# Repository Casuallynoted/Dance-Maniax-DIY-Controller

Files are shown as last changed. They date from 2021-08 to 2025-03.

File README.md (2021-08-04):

# Dance-Maniax-DIY-Controller
A DIY solution for creating a Dance Maniax controller, I wound up spending less than $40-50 on the whole thing.

# Requirements:

-Teensy 2.0 (This is what I used, but any microcontroller/arduino could theoretically be used for this)

-Four Sharp GP2Y0A21YK0F sensors (can also be used with other IR sensors from Sharp but this one has the farthest range)

-Soldering iron and solder

-A computer to program the microcontroller, but if you're using Stepmania you probably already have this!

# Optional, but always great to have:

-The Teensy 2.0 board uses a mini usb cable to connect to a computer but doesn't include one in the box. Other controllers may require different cable types so do your research!

-I wound up deciding to get Male to Female jumper cables to extend the sensors further out than the provided cables do. I used the ones here: https://www.amazon.com/gp/product/B06XRV92ZB/ref=ppx_yo_dt_b_asin_title_o00_s00?ie=UTF8&psc=1

-Respirator, no solder fumes for me!

-Helping Hands to hold the board while soldering (and while it was still in the DIY phase this doubled as my controller stand for a while)

-I'm working on a 3D-printable enclosure to make everything look nice and neat. No more wires! Will update with the model and printing instructions as soon as it's available.

# Hardware Setup

1. Once you've got all your materials, you'll want to begin by taking a look at the board you're using and the wiring diagram for the sensor. In this case if you're using a Teensy 2.0 and Sharp GP2Y0A21YK0F, you'll want to view these documents:

https://www.pololu.com/file/0J85/gp2y0a21yk0f.pdf
https://www.pjrc.com/teensy/card2b_rev5_web.pdf

Notice how the motion sensors have three wires- one for ground, one for power (vcc), and one for the actual data connection. Note which ones they are on the sensors as we don't want to solder the wrong wires into the wrong place. On our Teensy board, these will be going into the Ground, VCC, and A1-4 holes. Our sensors will all be sharing a single Ground and VCC hole, but we'll be soldering them one by one to the data holes.

2. We'll begin by heating up the soldering iron and readying the solder. Begin by getting all four ground cables into the Ground hole and creating a solder joint going out the bottom. I won't go too into detail about the soldering process but definitely view some soldering tutorials on YouTube if you have not soldered before. These should be pretty easy joints to do, so no stress!

Of course, once you're all done you'll want to do the same for the VCC/Power cables, all in one hole and soldered in nice and easy. We'll want to finish by soldering in A1, followed by A2-4. Make sure you don't combine two wires into the A holes. Just one hole per wire for this one. Once you're done, you should have six joints in total.

3. Once you're all done soldering, you're going to want to pick two sensors that will make up the left part of your controller, and two sensors that will make up the right part. They'll be back-to-back on top of each other with one sensor facing up toward the ceiling and the other facing down toward the floor. For now, I secured mine with just a bit of tape, and then used my helping hands to hold the combined sensors upright for play. However, I'm working on a 3D printable model that can be used to screw the sensors into a secure arcade-inspired enclosure that can be attached to a tripod mount. I figure it should make everything a lot easier going forward. For now, do what works best for you and find a good way to keep those sensors together and in a place where you can use them.

# Software Setup

Woot! You made it to the software side of things! This is where things get even easier! 

1. Once you've got your soldering out of the way, plug your usb connector into the microcontroller and your computer. We'll want to download the Arduino software (or if using a Teensy, Teensyduino). You can find the software here: https://www.pjrc.com/teensy/td_download.html. Users on Windows and Linux will have to download the official Arduno software and install Teensyduino on top of it, while Mac users will be able to just install Teensyduino.

2. Since the code is already premade, download the zip file for this repository. You can go ahead and open the Sharp_IR_DMX.ino file in the Arduino software. 
 
3. Select your board type in the Tools menu under Tools -> USB Type. If using a Teensy 2.0, we'll use Teensyduino -> Teensy 2.0. Set the USB type to "Keyboard + Mouse + Joystick", and make sure your Teensy is selected under the section called "Port".

4. We'll want to install the SharpIR library, because it tells our Teensy how to communicate back and forth with the motion sensors. To do this, we can go to Tools -> Manage Libraries, and make sure SharpIR is installed. If not, search for and install it.

5. Once that's all installed, we can go ahead and click verify on our code. It shouldn't produce any errors here, but if it does definitely post an issue on the github and I'll see what I can do to help! If all passes, go ahead and click the upload button. You may be asked to click the button once on the teensy to put it into programming mode. 

Note: The values used in this file are based on my play, but may not be accurate to your situation. If you notice that the sensors are too sensitive or not sensitive enough during play, adjust the lines that say "if average(number of sensor) > 100" and change that number to something higher or lower to adjust the sensitivity. Lower than 100 will typically trigger game button presses more often in response to motion, while higher will typically trigger game button presses less.

6. Once it has programmed and restarted, your controller is now off to the races! You can test it using build in utilities like Windows joystick testing settings, or you can go right into stepmania's input test and see what it turns up. From here, you can map the controller as you usually would. Congrats, you're up and running with a Dance Maniax controller!

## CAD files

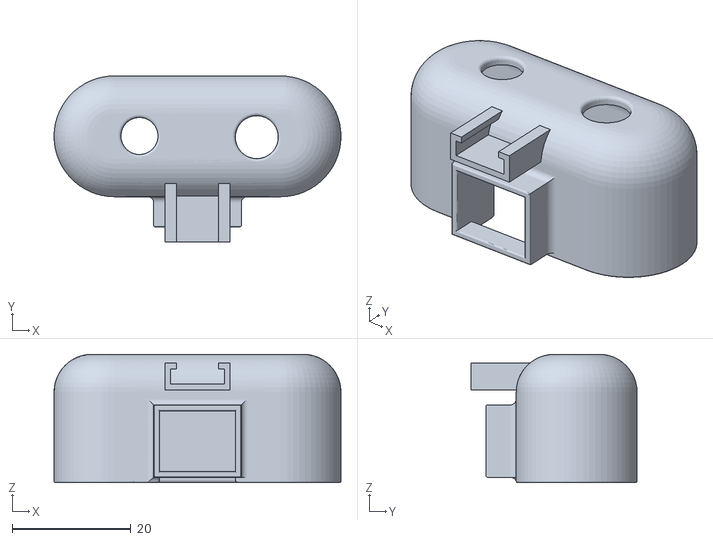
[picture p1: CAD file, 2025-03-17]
3D Printable STLs/sensor case.STL
48.3 x 27.9 x 21.6

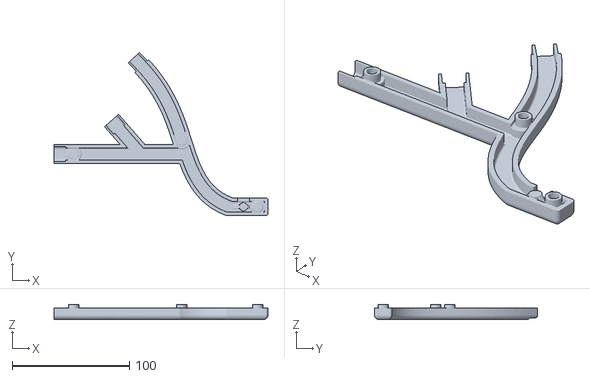
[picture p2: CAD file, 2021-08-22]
3D Printable STLs/Upper Left Arm.STL
182.7 x 139.3 x 13.0

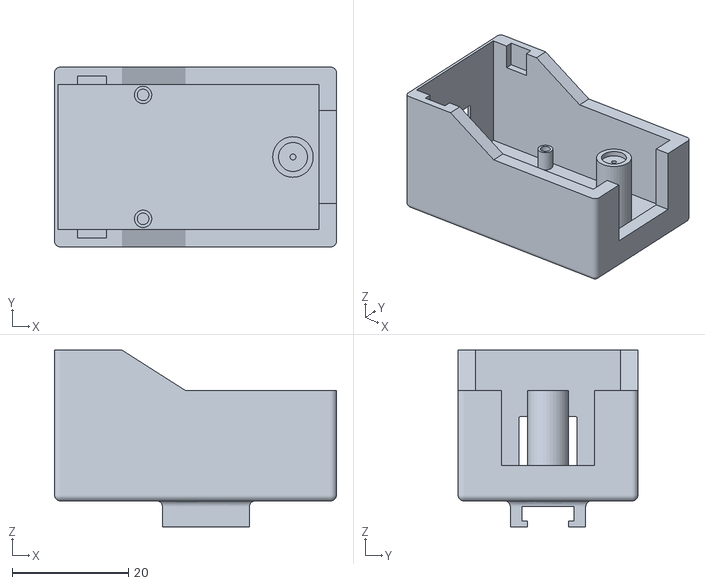
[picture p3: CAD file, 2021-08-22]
3D Printable STLs/Microcontroller Case.STL
48.6 x 31.0 x 30.5

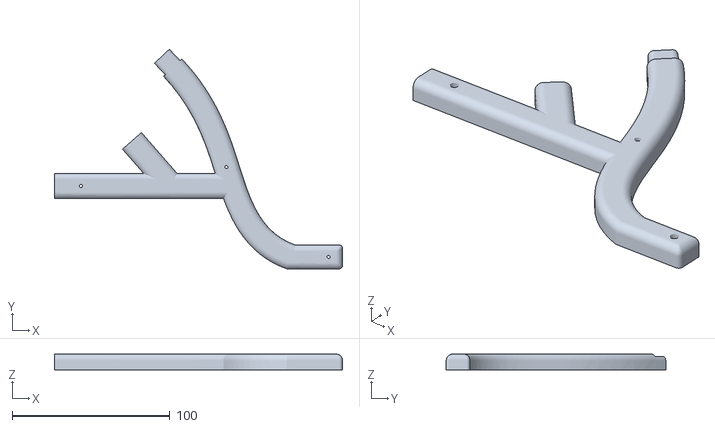
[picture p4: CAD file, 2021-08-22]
3D Printable STLs/Lower Left Arm.STL
182.7 x 139.3 x 10.0

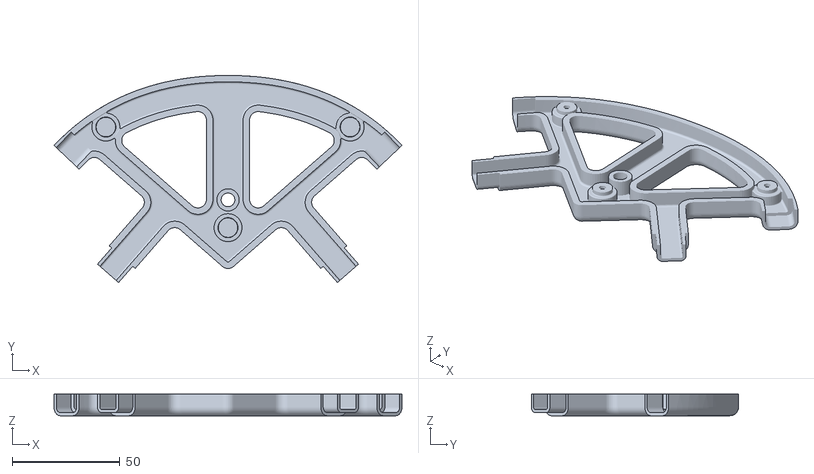
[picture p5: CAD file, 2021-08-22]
3D Printable STLs/Lower Center Casing.STL
161.6 x 96.2 x 10.00

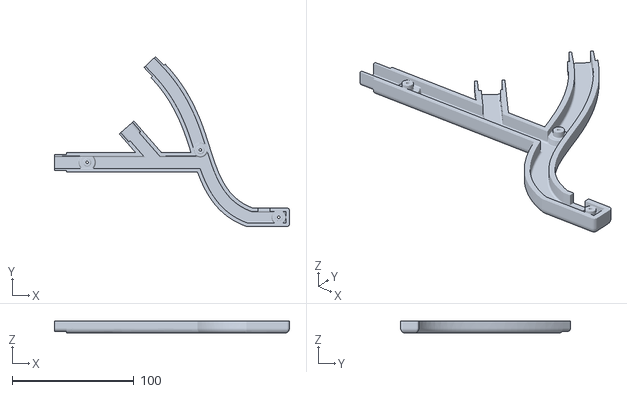
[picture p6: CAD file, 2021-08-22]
3D Printable STLs/Lower Right Arm.STL
192.7 x 139.3 x 10.00

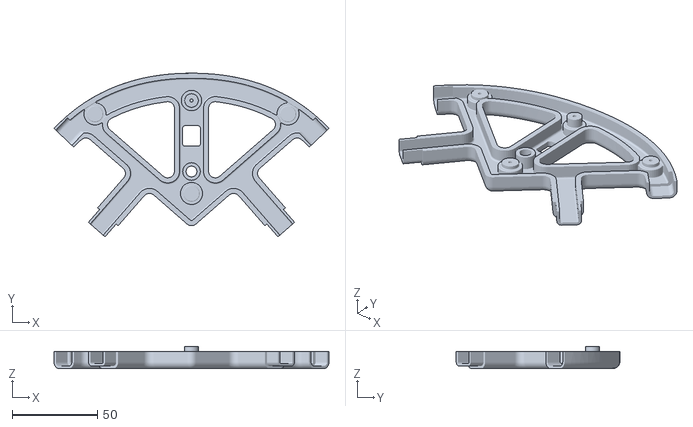
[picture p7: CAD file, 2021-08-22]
3D Printable STLs/Upper center casing.STL
161.6 x 96.2 x 13.0

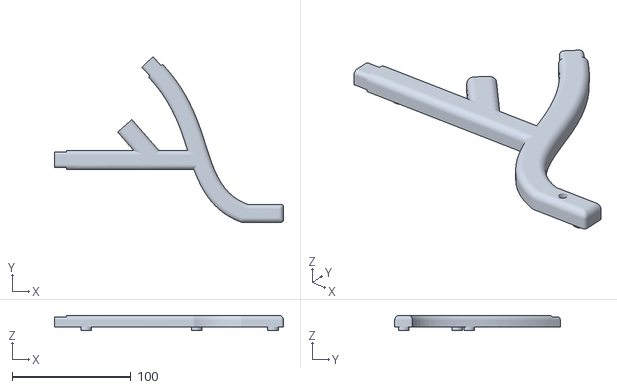
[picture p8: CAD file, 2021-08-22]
3D Printable STLs/Upper Right Arm.STL
192.7 x 139.3 x 13.0

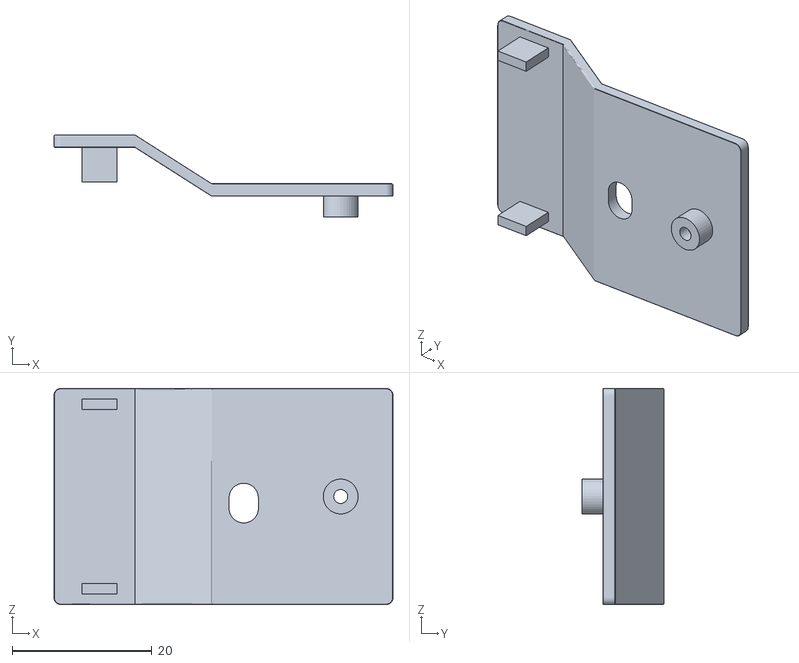
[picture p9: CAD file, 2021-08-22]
3D Printable STLs/Microcontroller Case Lid.STL
48.6 x 11.8 x 31.0

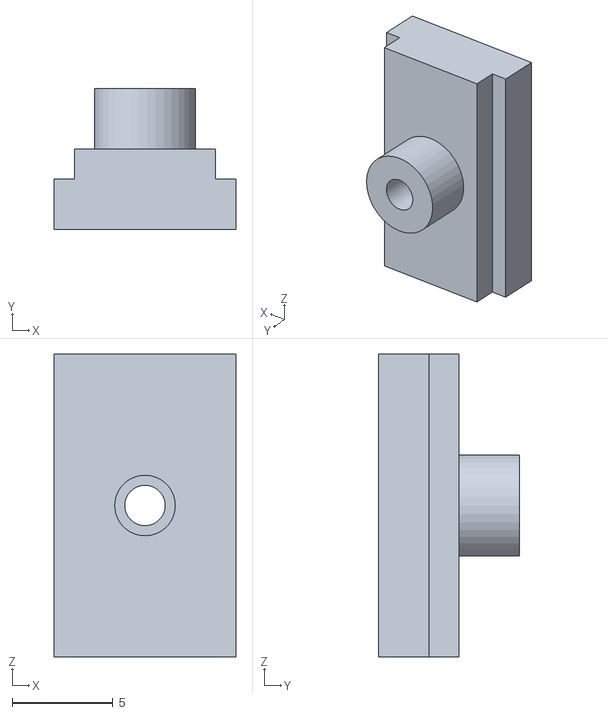
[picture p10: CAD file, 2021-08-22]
3D Printable STLs/Mount Piece (print three of these).STL
9.00 x 7.00 x 15.0

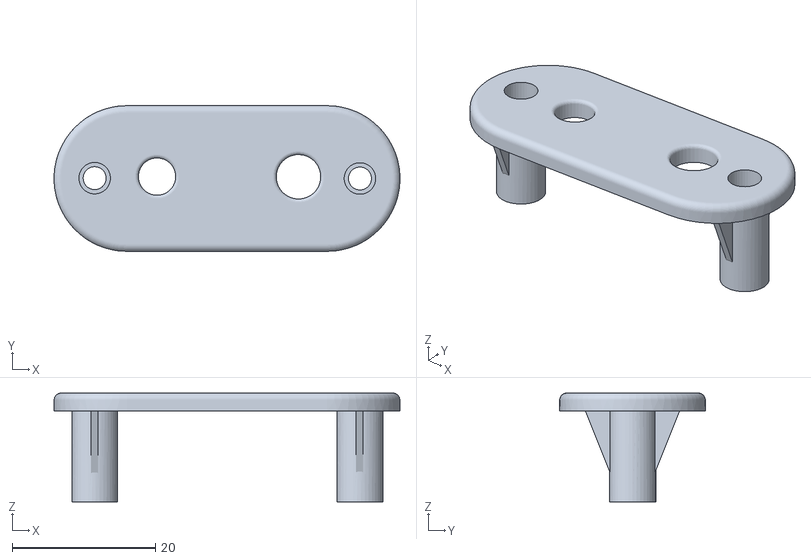
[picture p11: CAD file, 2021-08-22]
3D Printable STLs/Sensor Case Lid.STL
48.3 x 20.3 x 15.2

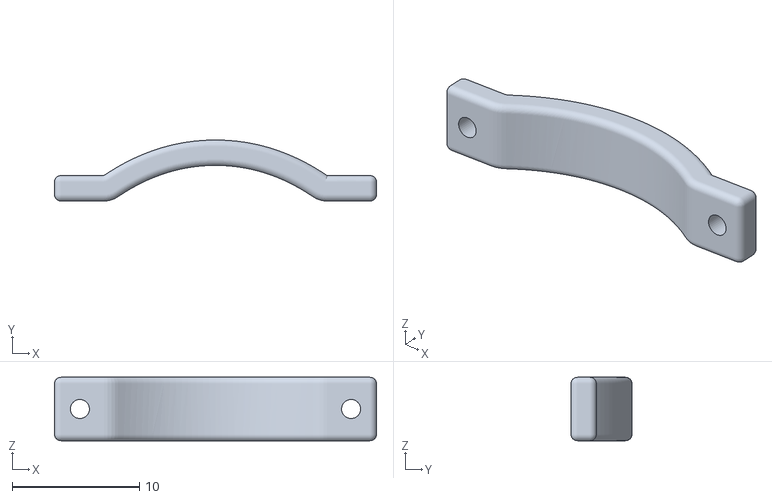
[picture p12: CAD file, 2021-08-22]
3D Printable STLs/Microcontroller Case Fastener (1M Screws).STL
25.4 x 4.80 x 5.00

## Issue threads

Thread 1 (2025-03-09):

Additional STL files and/or documentation?

Aerlena, 2025-03-09:
First, thanks so much for posting this project! I'm planning on building this soon.

Looking over the STL files, it seems like a few might be missing? I don't see how the sensors attach to the arms. There's a sensor case lid, but I don't see any files for a sensor case itself. It seems like that might be the missing piece.

It also isn't completely clear to me how the microcontroller case mounts to the center casing, but that looks easier to figure out without having to design a new piece.

Also, I'm not sure why the files say to print 3 of the mount pieces, it looks like you only really need one of these, for the microcontroller case?

If you have any extra STL files, or documentation of any kind for the enclosure, or even just pictures of the final assembly, those would be very useful!

And apologies if I am just missing something obvious, from my own naïvety. Thanks! -Aerlena

Casuallynoted, 2025-03-12:
OH SHOOT. Thank you for pointing this out- I must've missed the sensor cast STL when I originally uploaded it! I'm going to go digging through my old stuff and see if I can find it, thank you so much for pointing this out.

And the three mount pieces are one for the microcontroller case and two for the sensor cases. :)

I'll see if I can get that stl and then once I do I'll make sure to give you an idea of how it all goes together too! Thank you so much for checking this all out- it's a pretty old project of mine now and I've been hoping maybe someday someone could do it better than I did haha

Casuallynoted, 2025-03-17:
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

I believe I finally found it- it's possible this could be an older version though. I've added it to the repo, let me know if this works - and if you need any additional help, I'm happy to offer any assistance I can :)

Aerlena, 2025-05-06:
Great---thanks a lot for this! I've been very busy with work but hopefully will be able to get to this soon.

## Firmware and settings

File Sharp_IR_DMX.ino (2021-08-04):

/*
 * getDistance
 *
 * Example of using SharpIR library to calculate the distance beetween the sensor and an obstacle
 *
 * Created by Giuseppe Masino, 15 June 2016
 *
 * -----------------------------------------------------------------------------------
 *
 * Things that you need:
 * - Arduino
 * - A Sharp IR Sensor
 *
 *
 * The circuit:
 * - Arduino 5V -> Sensor's pin 1 (Vcc)
 * - Arduino GND -> Sensor's pin 2 (GND)
 * - Arduino pin A0 -> Sensor's pin 3 (Output)
 *
 *
 * See the Sharp sensor datasheet for the pin reference, the pin configuration is the same for all models.
 * There is the datasheet for the model GP2Y0A41SK0F:
 *
 * http://www.robotstore.it/open2b/var/product-files/78.pdf
 *
 */

//import the library in the sketch
#include <SharpIR.h>

// Define the number of samples to keep track of. The higher the number, the
// more the readings will be smoothed, but the slower the output will respond to
// the input. Using a constant rather than a normal variable lets us use this
// value to determine the size of the readings array.
const int numReadings = 10;

int readings[numReadings];      // the readings from the analog input
int readIndex = 0;              // the index of the current reading
int total = 0;                  // the running total
int average = 0;                // the average

int inputPin = A0;

const int numReadings2 = 10;

int readings2[numReadings2];      // the readings from the analog input
int readIndex2 = 0;              // the index of the current reading
int total2 = 0;                  // the running total
int average2 = 0;                // the average

int inputPin2 = A1;

const int numReadings3 = 10;

int readings3[numReadings3];      // the readings from the analog input
int readIndex3 = 0;              // the index of the current reading
int total3 = 0;                  // the running total
int average3 = 0;                // the average

int inputPin3 = A2;

const int numReadings4 = 10;

int readings4[numReadings4];      // the readings from the analog input
int readIndex4 = 0;              // the index of the current reading
int total4 = 0;                  // the running total
int average4 = 0;                // the average

int inputPin4 = A3;

//Create a new instance of the library
//Call the sensor "sensor"
//The model of the sensor is "GP2YA41SK0F"
//The sensor output pin is attached to the pin A0
SharpIR sensor( SharpIR::GP2Y0A21YK0F, A0 );
SharpIR sensor2( SharpIR::GP2Y0A21YK0F, A1 );
SharpIR sensor3( SharpIR::GP2Y0A21YK0F, A2 );
SharpIR sensor4( SharpIR::GP2Y0A21YK0F, A3 );


void setup()
{
  Serial.begin( 9600 ); //Enable the serial comunication
    // initialize all the readings to 0:
  for (int thisReading = 0; thisReading < numReadings; thisReading++) {
    readings[thisReading] = 0;
  }
    for (int thisReading2 = 0; thisReading2 < numReadings2; thisReading2++) {
    readings2[thisReading2] = 0;
  }

    for (int thisReading3 = 0; thisReading3 < numReadings3; thisReading3++) {
    readings3[thisReading3] = 0;
  }
      for (int thisReading4 = 0; thisReading4 < numReadings4; thisReading4++) {
    readings4[thisReading4] = 0;
  }
  
}

void loop()
{
    // subtract the last reading:
  total = total - readings[readIndex];
  // read from the sensor:
  readings[readIndex] = analogRead(inputPin);
  // add the reading to the total:
  total = total + readings[readIndex];
  // advance to the next position in the array:
  readIndex = readIndex + 1;

  // if we're at the end of the array...
  if (readIndex >= numReadings) {
    // ...wrap around to the beginning:
    readIndex = 0;
  }

  // calculate the average:
  average = total / numReadings;



    // subtract the last reading:
  total2 = total2 - readings2[readIndex2];
  // read from the sensor:
  readings2[readIndex2] = analogRead(inputPin2);
  // add the reading to the total:
  total2 = total2 + readings2[readIndex2];
  // advance to the next position in the array:
  readIndex2 = readIndex2 + 1;

  // if we're at the end of the array...
  if (readIndex2 >= numReadings2) {
    // ...wrap around to the beginning:
    readIndex2 = 0;
  }

  // calculate the average:
  average2 = total2 / numReadings2;


    // subtract the last reading:
  total3 = total3 - readings3[readIndex3];
  // read from the sensor:
  readings3[readIndex3] = analogRead(inputPin3);
  // add the reading to the total:
  total3 = total3 + readings3[readIndex3];
  // advance to the next position in the array:
  readIndex3 = readIndex3 + 1;

  // if we're at the end of the array...
  if (readIndex3 >= numReadings3) {
    // ...wrap around to the beginning:
    readIndex3 = 0;
  }

  // calculate the average:
  average3 = total3 / numReadings3;

      // subtract the last reading:
  total4= total4 - readings4[readIndex4];
  // read from the sensor:
  readings4[readIndex4] = analogRead(inputPin4);
  // add the reading to the total:
  total4 = total4 + readings4[readIndex4];
  // advance to the next position in the array:
  readIndex4 = readIndex4 + 1;

  // if we're at the end of the array...
  if (readIndex4 >= numReadings4) {
    // ...wrap around to the beginning:
    readIndex4 = 0;
  }

  // calculate the average:
  average4 = total4 / numReadings4;

  
  // send it to the computer as ASCII digits
  Serial.println(average3);
  delay(1);        // delay in between reads for stability
 // int distance = sensor.getDistance(); //Calculate the distance in centimeters and store the value in a variable
  //  int distance2 = sensor2.getDistance(); //Calculate the distance in centimeters and store the value in a variable
   //   int distance3 = sensor3.getDistance(); //Calculate the distance in centimeters and store the value in a variable
    //    int distance4 = sensor4.getDistance(); //Calculate the distance in centimeters and store the value in a variable

 // Serial.print("Mean distance: ");
 // Serial.print(distance3);
 // Serial.println(" cm");
   // Serial.println( distance2 ); //Print the value to the serial monitor
  //    Serial.println( distance3 ); //Print the value to the serial monitor
   //     Serial.println( distance4 ); //Print the value to the serial monitor
if(average > 100) {
    Joystick.button(1,1); 
}
else {
    Joystick.button(1,0);
}
if(average2 > 100) {
    Joystick.button(2,1);
}
else {
    Joystick.button(2,0);
}
if(average3 > 100) {
    Joystick.button(3,1);
}
else {
    Joystick.button(3,0);
}
if(average4 > 100) {
    Joystick.button(4,1);
}
else {
    Joystick.button(4,0);
}
  delay(1); 
}

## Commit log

2021-08-04 Added code for Teensy board
2021-08-22 Added 3D Enclosure Models
    [Lower Center Casing.STL, Lower Left Arm.STL, Lower Right Arm.STL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]
2025-03-17 Added missing sensor case STL
    [sensor case.STL]
